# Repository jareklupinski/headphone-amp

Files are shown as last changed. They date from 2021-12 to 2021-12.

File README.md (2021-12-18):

# headphone-amp
A simple headphone amp / signal buffer for balanced audio sources.

This design uses a TPS65131 to generate +-15V from a USB-C 5V input.

Originally, I wanted to use the INA1620, as its datasheet basically spells out that its intended use is as a headphone driver.

The opamp OPA1612 was chosen instead, as it seems to be basically the same chip, but without the integrated resistors, and was available from my assembly house at the time of production.

The PCB and face/backplates are sized for https://www.digikey.com/en/products/detail/bud-industries/EXN-23350-RDP/5886285, but any color should work ;)



schem

board

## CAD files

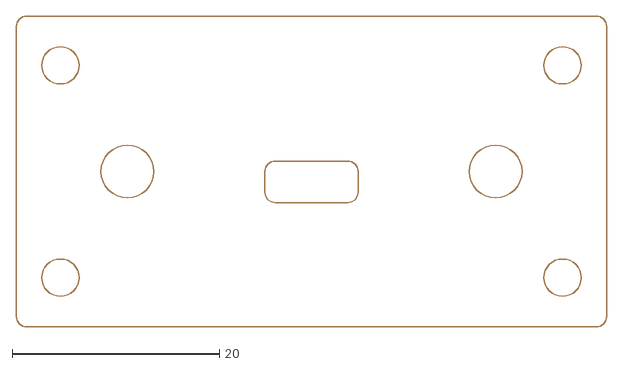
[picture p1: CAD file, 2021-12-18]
headphone-amp-faceplate.dxf
57.0 x 30.0

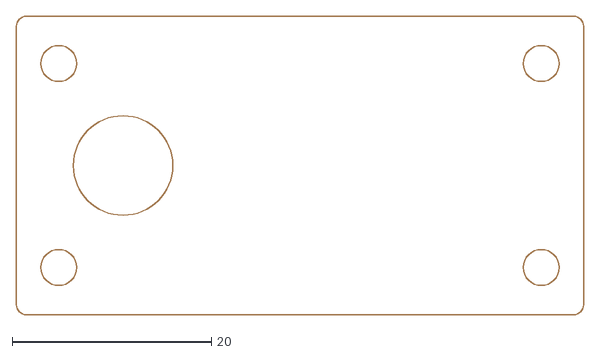
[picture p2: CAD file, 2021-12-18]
headphone-amp-backplate.dxf
57.0 x 30.0

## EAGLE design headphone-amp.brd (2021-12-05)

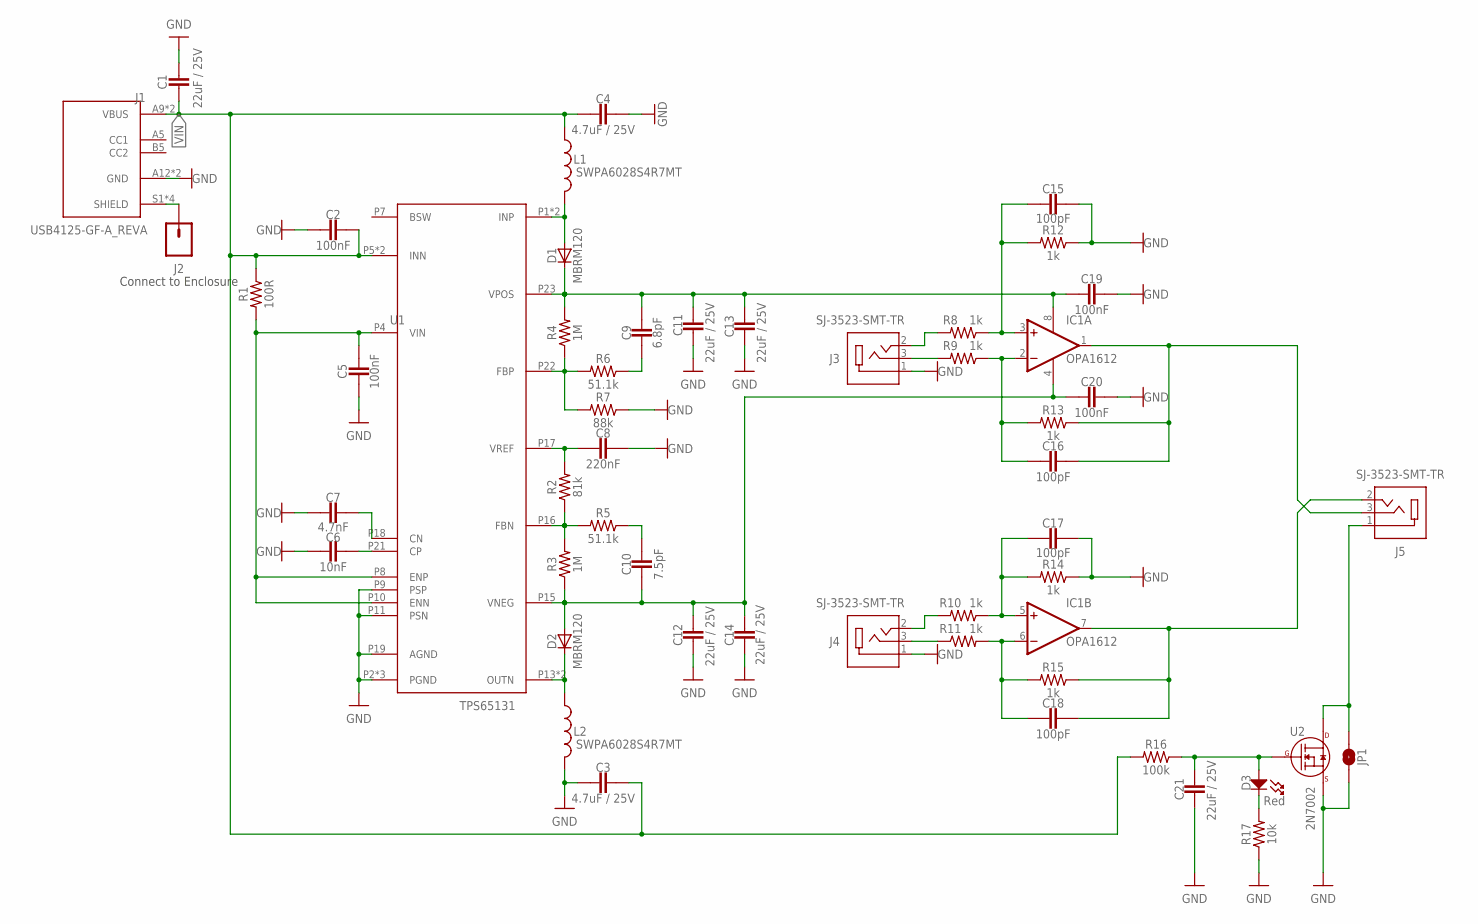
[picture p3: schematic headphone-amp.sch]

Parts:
C1, C11, C12, C13, C14, C21: 22uF / 25V; C0805
C2, C5, C19, C20: 100nF; C0402
C3, C4: 4.7uF / 25V; C0402
C6: 10nF; C0402
C7: 4.7nF; C0402
C8: 220nF; C0402
C9: 6.8pF; C0402
C10: 7.5pF; C0402
C15, C16, C17, C18: 100pF; C0402
D1, D2: MBRM120; POWERMITE
D3: Red; LED0603
IC1: OPA1612; SO08
J1: USB4125-GF-A_REVA; GCT_USB4125-GF-A_REVA
J2: CONN_01; 1X01
J3, J4, J5: SJ-3523-SMT-TR; CUI_SJ-3523-SMT-TR
JP1: JUMPER-SMT_2_NO_SILK; SMT-JUMPER_2_NO_SILK
L1, L2: SWPA6028S4R7MT; POWER-CHOKE_WE-TPC
R1: 100R; R0402
R2: 81k; R0402
R3, R4: 1M; R0402
R5, R6: 51.1k; R0402
R7: 88k; R0402
R8, R9, R10, R11, R12, R13, R14, R15: 1k; R0402
R16: 100k; R0402
R17: 10k; R0402
U1: TPS65131; QFN24-4X4-2
U2: 2N7002; SOT-23-3

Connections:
GND: C1.1, C2.1, C3.2, C4.1, C5.2, C6.2, C7.2, C8.1, C11.2, C12.2, C13.2, C14.2, C15.1, C17.1, C19.2, C20.2, C21.2, J1.A12 (GND), J1.B12 (GND), J3.1, J4.1, JP1.1, L2.2, R7.1, R12.1, R14.1, R17.1, U1.P2 (PGND), U1.P3 (PGND), U1.P9 (PSP), U1.P11 (PSN), U1.P19 (AGND), U1.PAD (PGND), U2.P$2 (SOURCE)
unnamed: C18.1, IC1.7 (OUT), J5.2, R15.1
unnamed: D1.P$2 (A), L1.2, U1.P1 (INP), U1.P24 (INP)
unnamed: C16.1, IC1.1 (OUT), J5.3, R13.1
unnamed: J1.S1 (SHIELD), J1.S2 (SHIELD), J1.S3 (SHIELD), J1.S4 (SHIELD), J2.1
unnamed: J3.3, R9.2
unnamed: R4.1, R6.2, R7.2, U1.P22 (FBP)
unnamed: C9.2, R6.1
unnamed: C8.2, R2.2, U1.P17 (VREF)
unnamed: R2.1, R3.2, R5.2, U1.P16 (FBN)
unnamed: C10.2, R5.1
unnamed: J3.2, R8.2
unnamed: D2.P$1 (C), L2.1, U1.P13 (OUTN), U1.P14 (OUTN)
unnamed: C6.1, U1.P21 (CP)
unnamed: C7.1, U1.P18 (CN)
unnamed: C18.2, IC1.6 (-IN), R11.2, R15.2
unnamed: C17.2, IC1.5 (+IN), R10.1, R14.2
unnamed: J4.2, R10.2
unnamed: J4.3, R11.1
unnamed: D3.CATHODE, R17.2
unnamed: C16.2, IC1.2 (-IN), R9.1, R13.2
unnamed: C15.2, IC1.3 (+IN), R8.1, R12.2
unnamed: C5.1, R1.2, U1.P4 (VIN), U1.P8 (ENP), U1.P10 (ENN)
unnamed: J5.1, JP1.2, U2.P$3 (DRAIN)
unnamed: C21.1, D3.ANODE, R16.1, U2.P$1 (GATE)
VDD: C9.1, C11.1, C13.1, C19.1, D1.P$1 (C), IC1.8 (V+), R4.2, U1.P23 (VPOS)
VEE: C10.1, C12.1, C14.1, C20.1, D2.P$2 (A), IC1.4 (V-), R3.1, U1.P15 (VNEG)
VIN: C1.2, C2.2, C3.1, C4.2, J1.A9 (VBUS), J1.B9 (VBUS), L1.1, R1.1, R16.2, U1.P5 (INN), U1.P6 (INN)

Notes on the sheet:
Connect to Enclosure

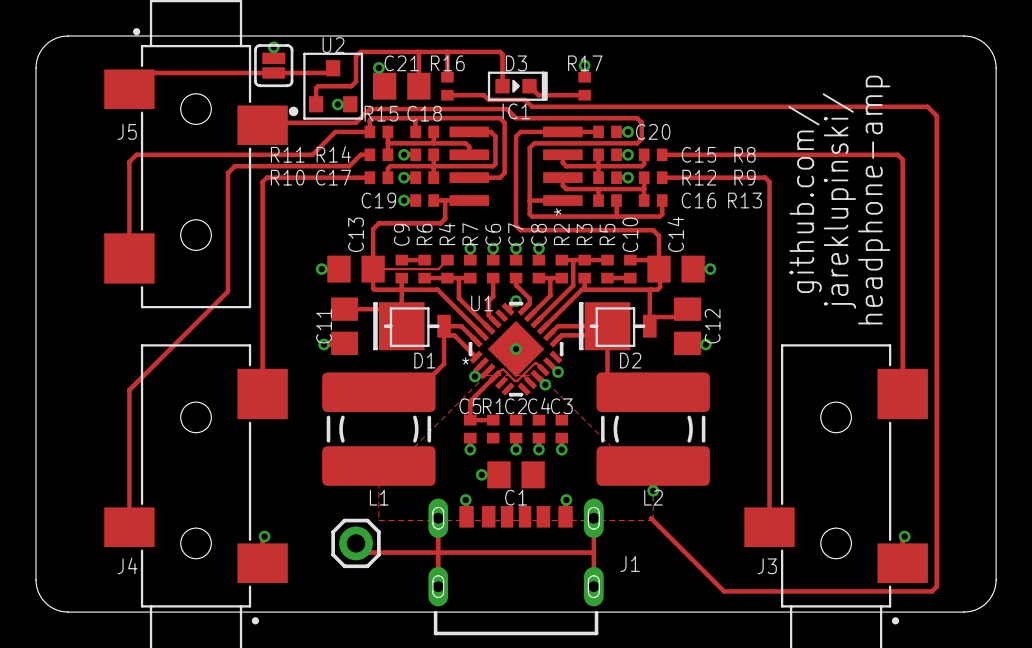
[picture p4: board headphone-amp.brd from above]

Board: 2 copper layers, 53.3 x 32.0 mm, 52 parts (0 on the bottom side), 28 nets.

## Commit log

2021-12-05 add power led, add soft start, fix op amp polarity
    [headphone-amp.brd, headphone-amp.sch]
2021-12-05 little routing change
    [headphone-amp.brd]

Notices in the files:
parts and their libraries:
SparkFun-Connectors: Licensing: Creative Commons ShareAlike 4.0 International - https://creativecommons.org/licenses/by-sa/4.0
